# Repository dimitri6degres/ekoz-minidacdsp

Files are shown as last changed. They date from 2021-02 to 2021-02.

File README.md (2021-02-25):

**THIS IS A WORK IN PROGRESS PROJECT**  
**ANY HELP IS WELCOME**

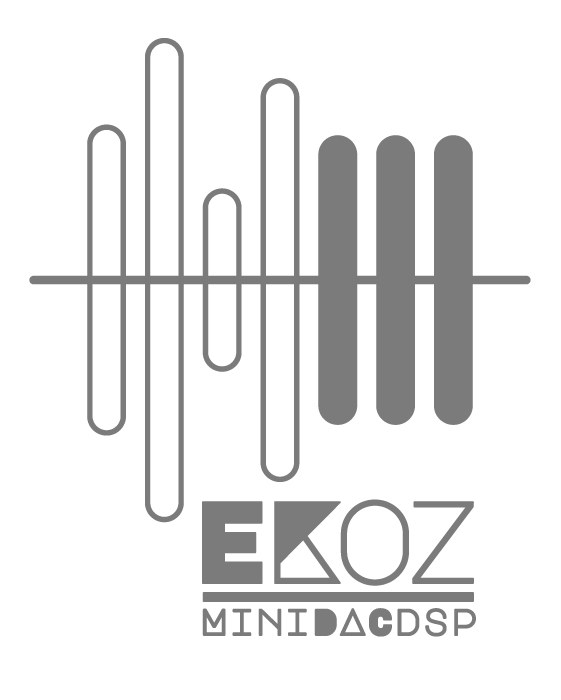
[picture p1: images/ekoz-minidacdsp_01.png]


## the prelude 

I wanted a dac with a "night mode" preset.  
Movies' soundtrack are awfull : we don't anderstand dialogs, but fx are very loud…  
it's impossible to watch a movie without playing permanently with the remote !

i've got a good stereo system (don't want HC 5.1…)  
i'm watching movies on a projector with an appleTV.  
So what i need is a small DAC with an optical input and stereo RCA output.  
After some googling, i don't see anything that can resolve my problem.  
The only way i've found was the <a href=https://www.hifiberry.com/shop/boards/hifiberry-dac-dsp>Hifiberry DAC+ DSP </a>  
so the **ekoz-minidacdsp project** was born...

## the design
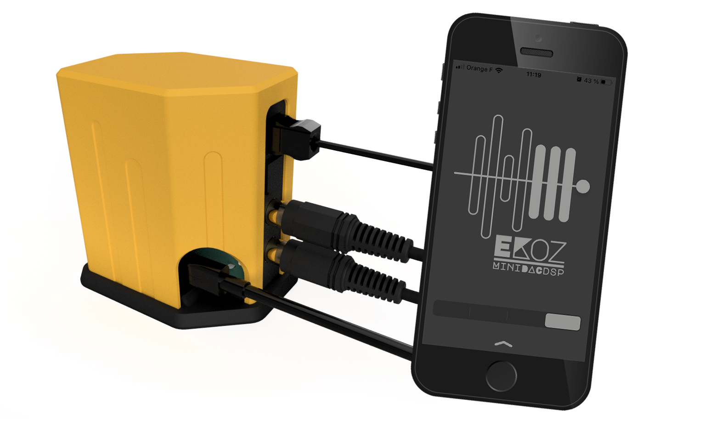
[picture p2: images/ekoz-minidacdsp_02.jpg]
  
The design is simple :  
the Hifiberry DAC+ DSP on a RaspberryPi Zero in a 3D printed box.  
the functionnalities are reduced to :  
INPUTS : bluetooth A2DP streaming & toslink  
OUTPUTS : ananlog RCA & digital toslink  
DSP : 4 presets (1 bypass + 3 levels of compression)  
APP : a companion app that communicate in bluetooth with the RPi to :  
select the DSP presets | change dac volume | activate BT pairing | activate Wifi | shutdown Rpi | reset DSP

## The 3D enclosure
In this design, the cards are plugged in rather than screwed.  
Everything is held by a single screw.  
the box is presented verticaly.
Cooling is provided by long slits.  
There is an empty space in the base to fit an SDcard adapter.

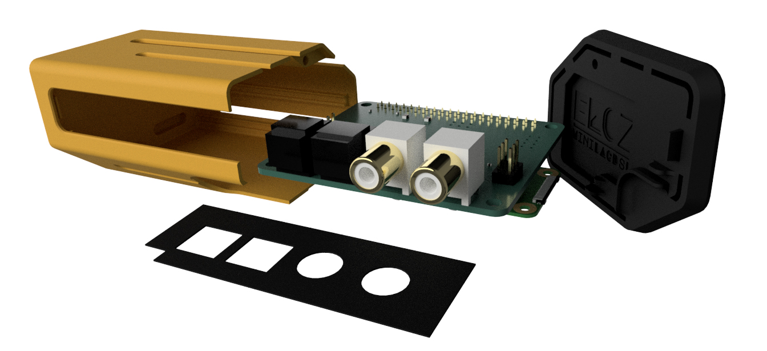
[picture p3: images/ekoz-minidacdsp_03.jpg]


STL files :  
<a href=https://github.com/dimitri6degres/ekoz-minidacdsp/blob/main/sources/3D_enclosure/ekoz-minidacdsp_base.stl>ekoz-minidacdsp_base.stl</a> | <a href=https://github.com/dimitri6degres/ekoz-minidacdsp/blob/main/sources/3D_enclosure/ekoz-minidacdsp_hood.stl>ekoz-minidacdsp_hood.stl</a> | <a href=https://github.com/dimitri6degres/ekoz-minidacdsp/blob/main/sources/3D_enclosure/ekoz-minidacdsp_strip.stl>ekoz-minidacdsp_strip.stl</a>

## the companion app
The interface is intentionally simplistic. 
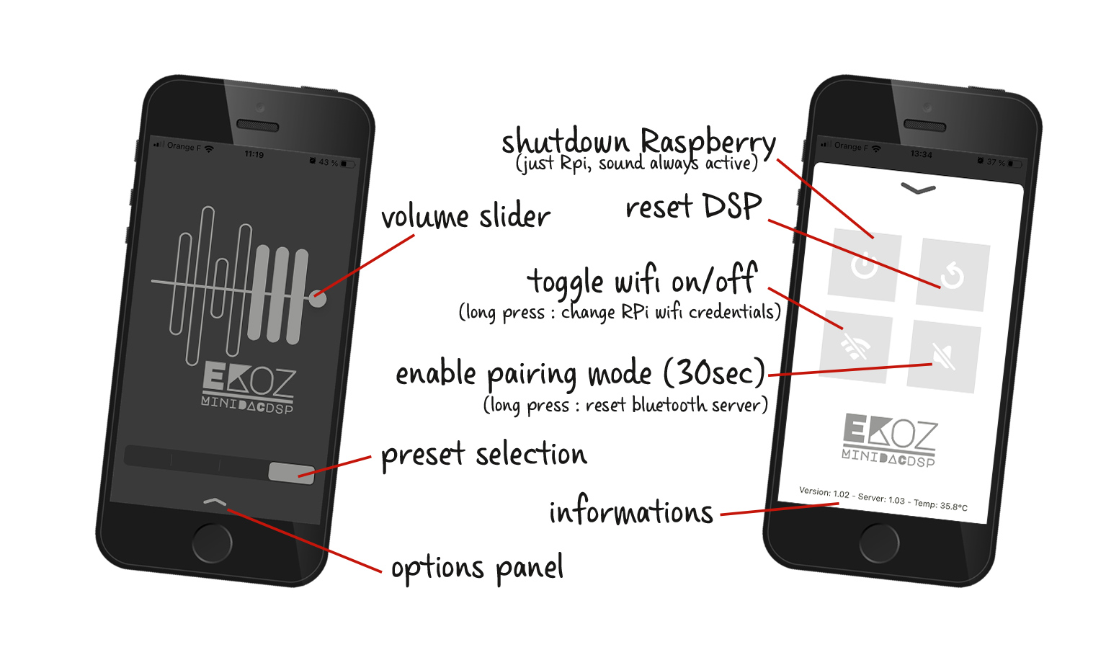
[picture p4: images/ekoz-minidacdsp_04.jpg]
   
It is currently only done for iphones...  
(looking for someone to make it available for androïd…)

## Basic installation
• install the app on your phone  
• mount the hifiberry DAC+ DSP module on top of the raspberry pi zero  
• download the <a href=https://github.com/dimitri6degres/ekoz-minidacdsp/releases/download/server/ekoz-minidacdsp_server.img.zip>last image file</a> from this repo  
• copy the os image on the sdcard (with something like <a href=https://www.balena.io/etcher/>balenaEtcher</a>)  
• install the card in the raspberry and boot it  
• open the app on your phone, wait for the dac to be detected  

## Manual installation
all needed files are ine the <a href=https://github.com/dimitri6degres/ekoz-minidacdsp/tree/main/boot>boot folder</a>.  
a script will do everything to set up the raspberry.  
• mount the hifiberry DAC+ DSP module on top of the raspberry pi zero  
• download and unzip the <a href=https://github.com/dimitri6degres/ekoz-minidacdsp/archive/main.zip>the files</a>  
• change your wifi credential in the wpa_supplicant.conf file  
• download the last <a href=https://www.raspberrypi.org/software/operating-systems/>raspberrypi os lite image</a>  
• copy the os image on the sdcard (i.g. <a href=https://www.balena.io/etcher/>balenaEtcher</a>)  
• copy the repo boot folder into the boot volume  
• install the card in the raspberry and boot it  
• ssh your raspberry (login "pi", password "raspberry")  
• launch command "sudo /boot/install.sh"  
• wait a quite long time for the raspberry to install everything (20min?)  
• the raspberry must tell you to reboot to finish the install  
• install the app on your phone  
• open the app and wait for the dac to be detected  

## how it works

-- DSP on hifiberry card  
the dsp is programmed with <a href=https://www.analog.com/en/design-center/evaluation-hardware-and-software/software/ss_sigst_02.html#>sigmastudio</a> to have 4 presets (1 bypass, 3 levels of compression)  
the project file (<a href=https://github.com/dimitri6degres/ekoz-minidacdsp/tree/main/sources/sigmastudio>ekoz-minidacdsp.dspproj</a>) structure is made from 4 "shells" that can be modified  
(looking for acoustics pros to improve settings)  
There is no detection or switch for inputs, raspberry and toslink signals overlap  
the xml profile file is tagged with registers for the volume and the channel's switch  

-- services on Raspberry  
in normal mode, wifi is disabled, bluetooth enabled but not discoverable nor pairable.  
a GATT server is launched with a python script to communicate between the phone's app and the dsp.  
the script uses the registers to read and modify on the fly the values in the dsp.  
BlueAlsa is used to stream bluetooth A2DP music.

## the projects that have helped me…
I'm not a code developper or expert with rapsberry, dsp, python…  
but google and github is a perfect source of inspiration, so thanks to:  
<a href=https://stackoverflow.com>Stackoverflow.com, this wealth of information</a>  
<a href=https://www.hifiberry.com/modify-dsp-registers-on-the-fly/>the hifiberry forum, guides and github</a>  
<a href=https://github.com/Douglas6/cputemp>douglas6 / cputemp</a>  
<a href=https://github.com/nicokaiser/rpi-audio-receiver>nicokaiser / rpi-audio-receiver</a>  
<a href=https://www.raywenderlich.com/231-core-bluetooth-tutorial-for-ios-heart-rate-monitor>RayWenderlich.com</a>  
and others…

## what's next?
This project is not finished. I just drew the outlines.  
What i did is just DIY, even if it doesn't work too badly...  
it's enough for me, but surely not enough for sharing.  
(I'd never use raspberry, python, bluetooth before this project)  
So it's should be nice if anyone who has python knowledge can re-write the python script,  
sound engineers help to get better compressor / audio settings,  
a raspberry/linux expert to rewrite the install script,  
a swift coder to improve the ios app,  
a android coder to make it available for all,
maybe a web coder to make a web version...  
(And somebody to re-write all what you read, because i've got a quite bad english…)

## how to get an ekoz-minidacsdsp?
This is not a commercial project, you should be able to build it by yourself. it's quite easy!  
But if you prefer to get one already working, contact me.

## License
<p xmlns:cc="http://creativecommons.org/ns#" xmlns:dct="http://purl.org/dc/terms/"><a property="dct:title" rel="cc:attributionURL" href="https://github.com/dimitri6degres/ekoz-minidacdsp">ekoz-minidacdsp</a> by <a rel="cc:attributionURL dct:creator" property="cc:attributionName" href="https://github.com/dimitri6degres/ekoz-minidacdsp">Dimitri Fontaine</a> is licensed under <a href="http://creativecommons.org/licenses/by-nc/4.0/?ref=chooser-v1" target="_blank" rel="license noopener noreferrer" style="display:inline-block;">CC BY-NC 4.0  

</a></p>

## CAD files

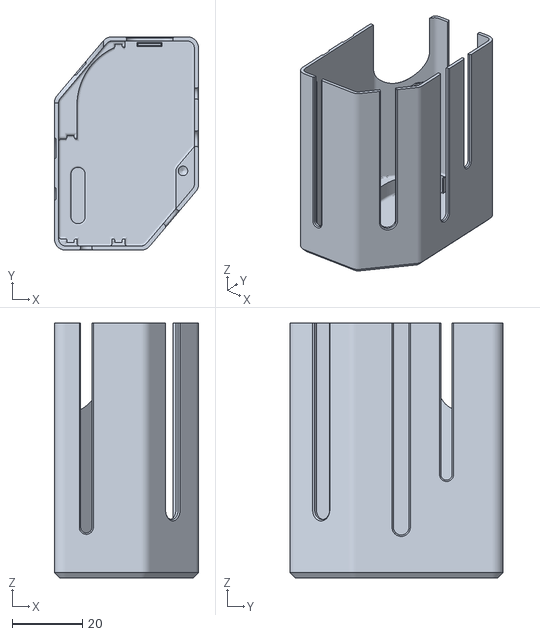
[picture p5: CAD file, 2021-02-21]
sources/3D_enclosure/ekoz-minidacdsp_hood.stl
40.9 x 60.6 x 72.4

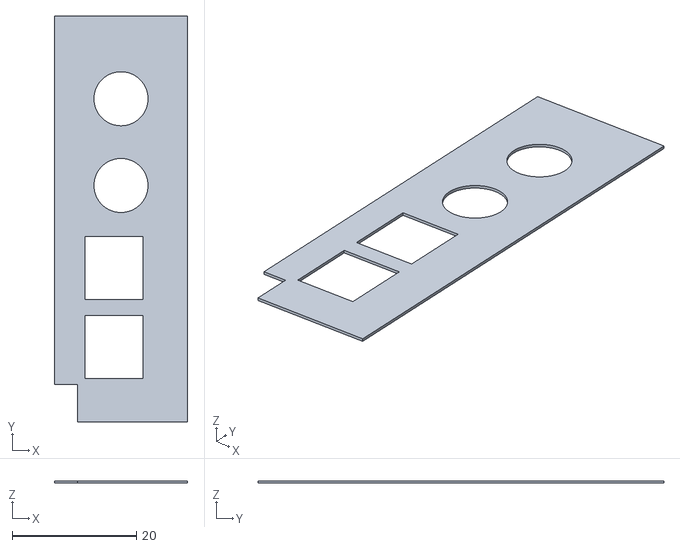
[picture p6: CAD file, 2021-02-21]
sources/3D_enclosure/ekoz-minidacdsp_strip.stl
21.4 x 65.4 x 0.4

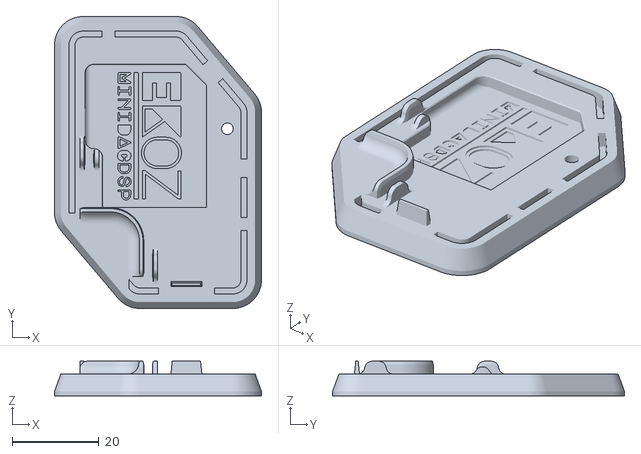
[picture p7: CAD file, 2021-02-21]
sources/3D_enclosure/ekoz-minidacdsp_base.stl
47.9 x 67.5 x 8.00

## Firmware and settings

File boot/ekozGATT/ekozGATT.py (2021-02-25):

#!/usr/bin/python3

"""
ekoz-minidacdsp by Dimitri Fontaine is licensed under CC BY-NC 4.0.
To view a copy of this license, visit http://creativecommons.org/licenses/by-nc/4.0/
"""

import dbus
import sys
import subprocess
import os
import fileinput
import time
import xml.etree.ElementTree as ET

from threading import Timer
from advertisement import Advertisement
from service import Application, Service, Characteristic, Descriptor
from gpiozero import CPUTemperature

GATT_CHRC_IFACE = "org.bluez.GattCharacteristic1"

GATT_CHRC_IFACE2 = "org.bluez.GattCharacteristic1"
NOTIFY_TIMEOUT = 5000

SERVER_VERSION = "V1.04"

class EkozminidacdspAdvertisement(Advertisement):
    def __init__(self, index):
        Advertisement.__init__(self, index, "peripheral")
        self.add_local_name("ekoz-minidacdsp")
        self.include_tx_power = True



# register-service 7ba6d936-6deb-11eb-9439-0242ac130002
 
        
        
class EkozminidacdspService(Service):
    EKOZMINIDACDSP_SVC_UUID = "00000001-6deb-11eb-9439-0242ac130002"

    def __init__(self, index):

        self.wifi = True
        cmd = 'echo discoverable no | sudo  bluetoothctl && echo pairable no | sudo  bluetoothctl'
        os.system(cmd)
        print("make bluetooth pairable no")
        self.bluetooth = False
        
        root = ET.parse('/var/lib/hifiberry/dspprogram.xml')
        for temp in root.findall('.//metadata'):
                if temp.get("type") == "channelSelectRegister":
                    print(temp)
                    self.channelRegHex = hex(int(temp.text))
                elif temp.get("type") == "volumeControlRegister":
                    print(temp)
                    self.volumeRegHex = hex(int(temp.text))
        
        self.volume = self.read_volume()
        self.channel = self.read_channel()

        Service.__init__(self, index, self.EKOZMINIDACDSP_SVC_UUID, True)
        
        self.add_characteristic(SystemCharacteristic(self))
        self.add_characteristic(WifiCharacteristic(self))
        self.add_characteristic(DSPCharacteristic(self))

        print("init service ok")

        
    def read_channel(self):
        bashCmd = ["dsptoolkit", "read-int", self.channelRegHex]
        process = subprocess.Popen(bashCmd, stdout=subprocess.PIPE)
        output, error = process.communicate()
        output = output.rstrip().decode("utf-8")

        channel = int(output)

        return str(int(channel))

    def read_volume(self):
        bashCmd = ["dsptoolkit", "read-int", self.volumeRegHex]
        process = subprocess.Popen(bashCmd, stdout=subprocess.PIPE)
        output, error = process.communicate()
        output = output.rstrip().decode("utf-8")

        volume = int(output)
        volume = ((volume - 1677722) * 100) / 15099494

        return str(int(volume))



    def is_wifi_up(self):
    
        f = open('/sys/class/net/wlan0/operstate', 'r')
        text = f.readline().rstrip()
        f.close()
        output = False
        if str(text)[0] == 'u':
            output = True
        return output



    def set_new_password(self, credential):
       
        os.system('sudo mount -o remount,rw /')
        os.system('ifconfig wlan0 down')
     
        print("WifiPass")

        
        f = open('/etc/wpa_supplicant/wpa_supplicant.conf', 'r')
        in_file = f.readlines()
        print(in_file)
        f.close()

        newcredential = credential.split("&&&")
        print(newcredential[0][1:])
        print(newcredential[1])
        print(newcredential[2])
        
        out_file = []
        for line in in_file:
            print(line)
            if line.startswith("country"):
                    line = 'country='+newcredential[0][1:]+'\n'
            if line.startswith("     ssid"):
                    line = '     ssid='+'"'+newcredential[1]+'"'+'\n'
            if line.startswith("     psk"):
                    line = '     psk='+'"'+newcredential[2]+'"'+'\n'
            out_file.append(line)
            
        f = open('/etc/wpa_supplicant/wpa_supplicant.conf', 'w')
        for line in out_file:
            f.write(line)
        f.close()

        os.system('ifconfig wlan0 up')
        os.system('sudo mount -o remount,ro /')
 
 
        

        
        
class SystemCharacteristic(Characteristic):
    SYS_CHARACTERISTIC_UUID = "00000002-6deb-11eb-9439-0242ac130002"

    def __init__(self, service):
        Characteristic.__init__(
                self, self.SYS_CHARACTERISTIC_UUID,
                ["notify", "write-without-response"], service)
        self.notifying = False
        print("init system ok")
        
        
    def WriteValue(self, value, options):
        val = str(value[0]).upper()
        if val.startswith("S"):
            os.system('sudo halt')
        elif val.startswith("R"):
            os.system('sudo reboot')
            
            
    def get_temperature(self):
        value = []

        cpu = CPUTemperature()
        temp = cpu.temperature

#        print(temp)
        strtemp = str(round(temp, 1))
        for c in strtemp:
            value.append(dbus.Byte(c.encode()))

        return value

    def set_temperature_callback(self):
        if self.notifying:
            value = self.get_temperature()
            self.PropertiesChanged(GATT_CHRC_IFACE, {"Value": value}, [])

        return self.notifying

    def StartNotify(self):
        if self.notifying:
            print('Already notifying, nothing to do')
            return
        self.notifying = True

        value = []
        desc = SERVER_VERSION
        for c in desc:
            value.append(dbus.Byte(c.encode()))
        self.PropertiesChanged(GATT_CHRC_IFACE, {"Value": value}, [])
        self.add_timeout(NOTIFY_TIMEOUT, self.set_temperature_callback)

    def StopNotify(self):
        self.notifying = False
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

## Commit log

2021-02-20 add ios app
    ios
    [config.txt]
2021-02-21 adding files
    [ekoz-minidacdsp_base.stl, ekoz-minidacdsp_hood.stl, ekoz-minidacdsp_strip.stl]
2021-02-22 ios mod
    [config.txt]

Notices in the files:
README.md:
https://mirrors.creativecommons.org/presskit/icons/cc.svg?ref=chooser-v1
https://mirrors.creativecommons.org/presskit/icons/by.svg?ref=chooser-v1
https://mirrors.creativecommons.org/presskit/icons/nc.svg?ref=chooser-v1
